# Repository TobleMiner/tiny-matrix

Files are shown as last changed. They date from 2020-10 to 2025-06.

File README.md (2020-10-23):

Tiny LED matrix
===============

This board is a tiny 8x8 monochrome LED matrix powered by a STM32F030. The board is
just 11x11mm in size and fully JLCPCB assembly ready. The board has been panelized
in a 2x3 grid to use the available space on JLC's PCBs more efficinetly.  
The device uses a novel, BGA style assembly procedure to achieve the smallest footprint
possible.

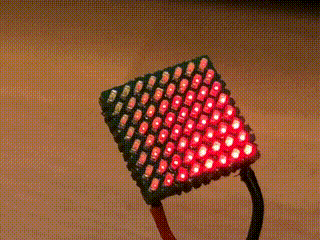
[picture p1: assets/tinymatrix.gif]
matrix animation showcase


# Ordering
When ordering through JLC there is a small tradeoff to be made. You can either order the
boards with 1mm thickness and will need to perform a small mechanical modification on
your TC2030 but get the smalles formfactor possible or order the boards in 1.6mm thickness
making your board stack thicker but sparing you from hacking up your TC2030.  
If you are not into placing components like A LOT I'd recommend using JLCs assembly service.

# Programming
The boards are fully functional while in the panel. I'd recommend leaving at least one
pair of boards inside the panel since the TC2030 cable can not be fixed to board easily
anymore once the board sandwich has been assembled.
Note that you might have to file down the allignment pins of the TC2030 if you want to
use it with assembled boards, since they are too long for the pogo pins to reach the pads
with a 1mm PCB.

# Assembly
While the matrix boards are fully functional while inside the frame they are intended to
be soldered back to back. To solder the boards together first remove them from the panel.
After that wet the backsides of the boards with a liberal amount of good quality flux.
Then drag a soldering iron wetted with lots of solder over the testpoints on the backside
of the board. This should create fairly uniform solder balls ontop of the pads. Once all
boards are preapred with solder balls apply more flux and stick one controller board and
one LED board together. Make sure they are alligned properly. Now you can reflow the two
boards together. You can do this either manually with hot air or in a reflow oven. Situate
the stacked boards LEDs down, since they are the most temperature sensitive parts. If you
have any level of familarity with soldering BGA components you will notice when reflow is
complete right away. Don't be afraid to heat the boards for a little longer, the STM32F030
seem to be able to take quite a lot of abuse.

# Firmware
The directory `firmware` contains a simple example displaying the pattern from the gif
above.

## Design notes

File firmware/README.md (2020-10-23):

Tinymatrix firmware
===================

A simple firmware example for the tinymatrix.

Requires arm-none-eabi toolchain.

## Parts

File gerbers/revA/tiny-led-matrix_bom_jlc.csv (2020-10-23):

Comment | Designator | Footprint | LCSC Part #
10uF | C1 | C_0402_1005Metric | C15525
100nF | C3,C2,C4 | C_0402_1005Metric | C1525
LED | D1,D2,D3,D4,D5,D6,D7,D8,D9,D10,D11,D12,D13,D14,D15,D16,D17,D18,D19,D20,D21,D22,D23,D24,D25,D26,D27,D28,D29,D30,D31,D32,D33,D34,D35,D36,D37,D38,D39,D40,D41,D42,D43,D44,D45,D46,D47,D48,D49,D50,D51,D52,D53,D54,D55,D56,D57,D58,D59,D60,D61,D62,D63,D64 | LED_0402_1005Metric | C165980
1kR | R1 | R_0402_1005Metric | C11702
1kR | RN1,RN2 | R_Array_Concave_4x0402 | C25726
STM32F030F4Px | U1 | TSSOP-20_4.4x6.5mm_P0.65mm | C89040

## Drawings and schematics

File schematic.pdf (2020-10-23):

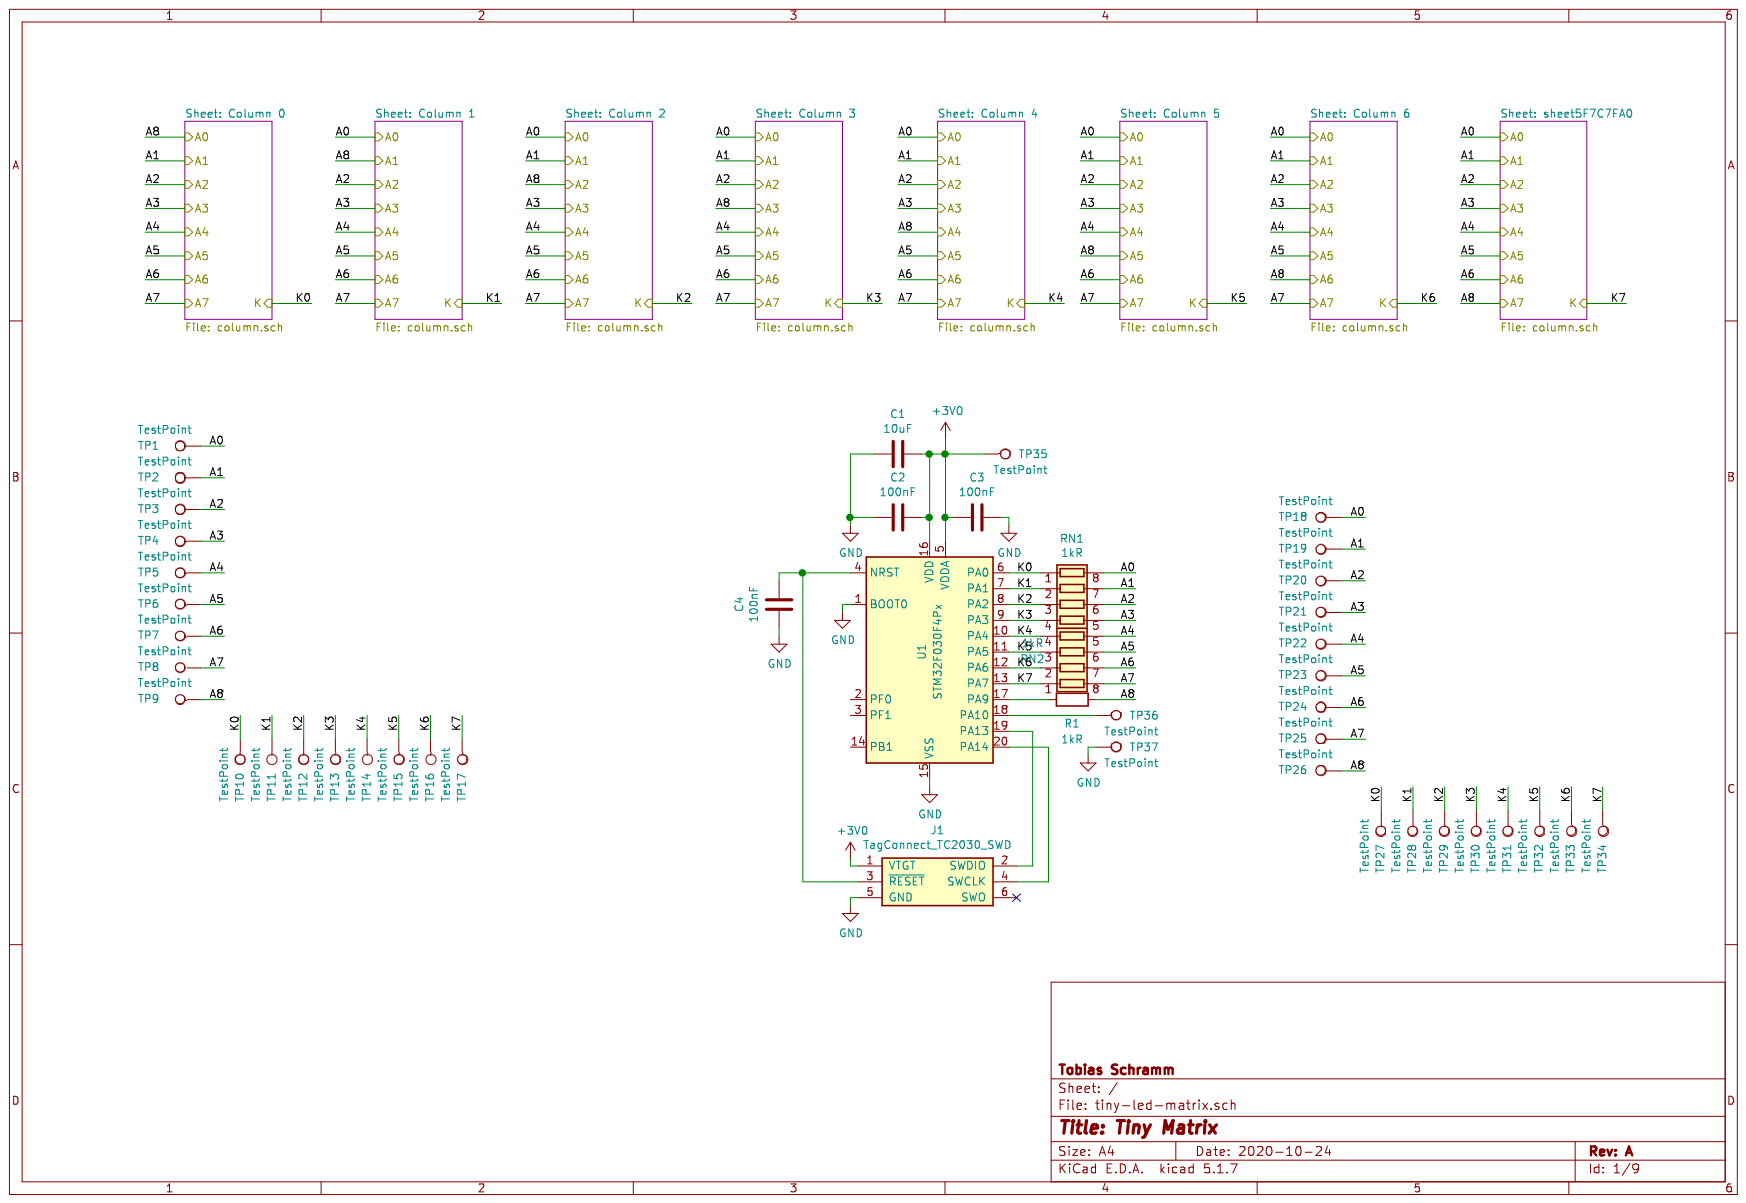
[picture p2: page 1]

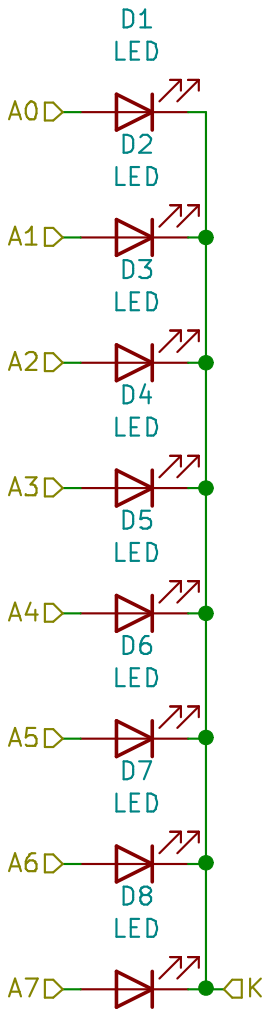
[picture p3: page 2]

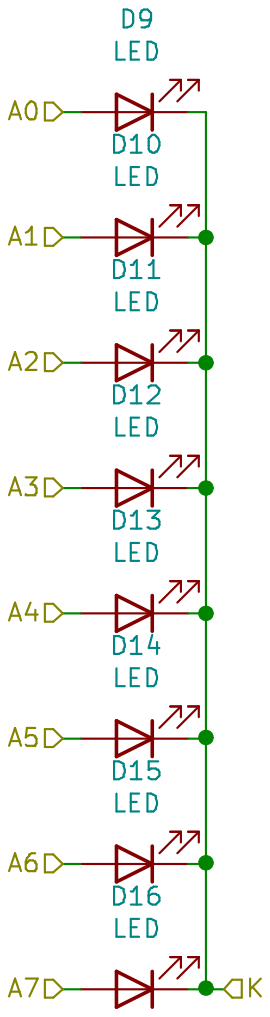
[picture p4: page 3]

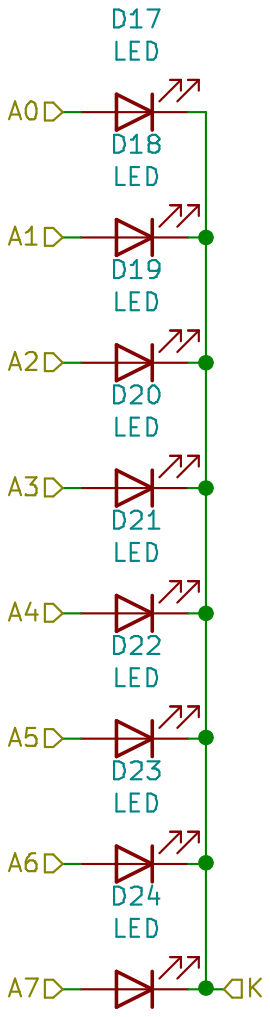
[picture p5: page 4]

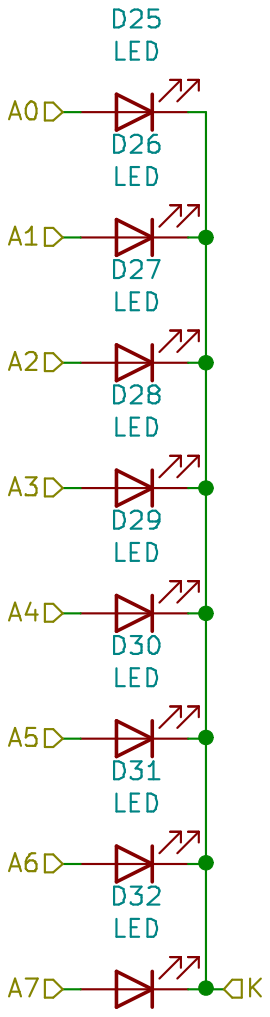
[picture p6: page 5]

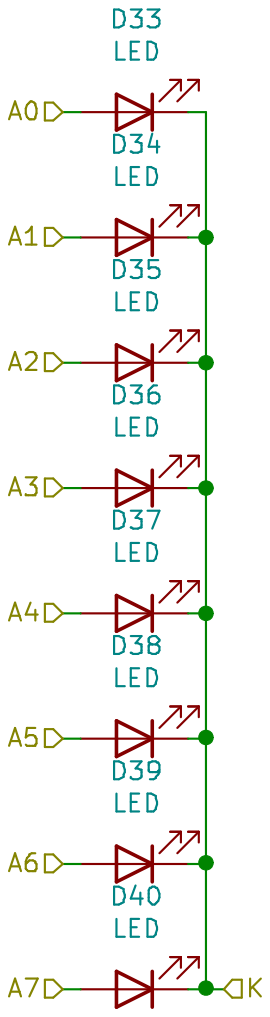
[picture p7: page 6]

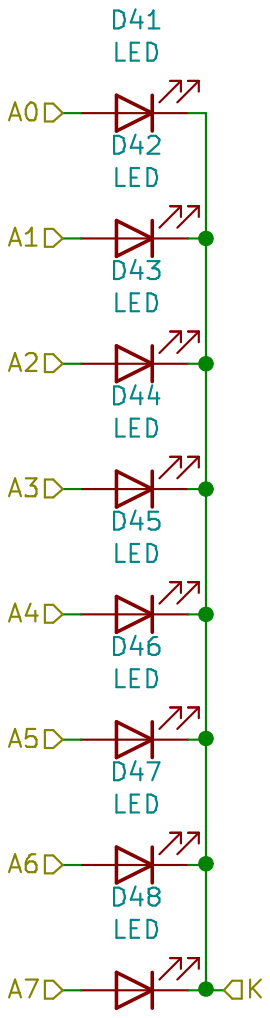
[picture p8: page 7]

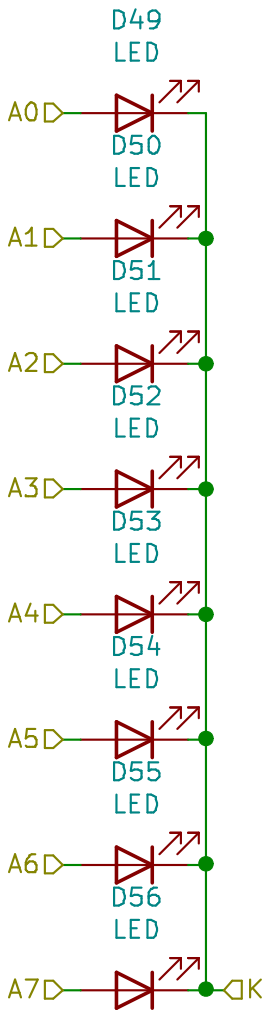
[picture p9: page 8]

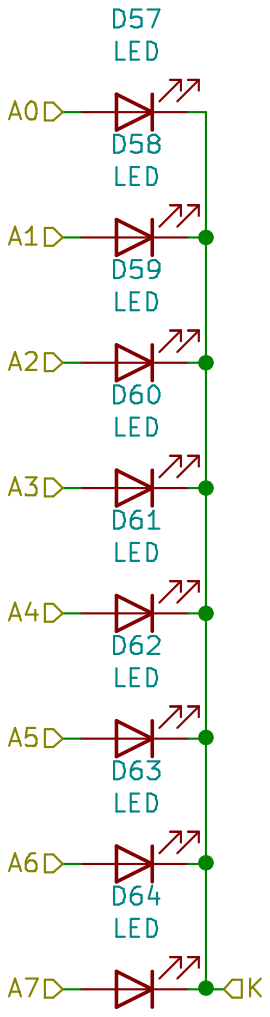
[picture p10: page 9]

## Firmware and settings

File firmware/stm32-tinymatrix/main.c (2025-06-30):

#include <stddef.h>
#include <stdbool.h>
#include <stdio.h>
#include <string.h>
#include <math.h>
#define M_PI 3.14159265358979323846264338328


#include <libopencm3/cm3/nvic.h>
#include <libopencm3/stm32/gpio.h>
#include <libopencm3/stm32/rcc.h>
#include <libopencm3/stm32/timer.h>

#include "game_of_life_vec32.h"
#include "rng.h"

#define ARRAY_SIZE(arr_) (sizeof((arr_)) / sizeof(*(arr_)))
#define ABS(x_) ((x_) > 0 ? (x_) : -(x_))

const uint8_t gamma8[] = {
    0,  0,  0,  0,  0,  0,  0,  0,  0,  0,  0,  0,  0,  0,  0,  0,
    0,  0,  0,  0,  0,  0,  0,  0,  0,  0,  0,  0,  1,  1,  1,  1,
    1,  1,  1,  1,  1,  1,  1,  1,  1,  2,  2,  2,  2,  2,  2,  2,
    2,  3,  3,  3,  3,  3,  3,  3,  4,  4,  4,  4,  4,  5,  5,  5,
    5,  6,  6,  6,  6,  7,  7,  7,  7,  8,  8,  8,  9,  9,  9, 10,
   10, 10, 11, 11, 11, 12, 12, 13, 13, 13, 14, 14, 15, 15, 16, 16,
   17, 17, 18, 18, 19, 19, 20, 20, 21, 21, 22, 22, 23, 24, 24, 25,
   25, 26, 27, 27, 28, 29, 29, 30, 31, 32, 32, 33, 34, 35, 35, 36,
   37, 38, 39, 39, 40, 41, 42, 43, 44, 45, 46, 47, 48, 49, 50, 50,
   51, 52, 54, 55, 56, 57, 58, 59, 60, 61, 62, 63, 64, 66, 67, 68,
   69, 70, 72, 73, 74, 75, 77, 78, 79, 81, 82, 83, 85, 86, 87, 89,
   90, 92, 93, 95, 96, 98, 99,101,102,104,105,107,109,110,112,114,
  115,117,119,120,122,124,126,127,129,131,133,135,137,138,140,142,
  144,146,148,150,152,154,156,158,160,162,164,167,169,171,173,175,
  177,180,182,184,186,189,191,193,196,198,200,203,205,208,210,213,
  215,218,220,223,225,228,231,233,236,239,241,244,247,249,252,255 };

static volatile uint8_t fb_g[8 * 8] = { 0 };

#define FIELD_COMPRESSION 1

/* Cycle through all LEDs, one at a time */
//#define LED_TEST
//#define SINE_FIELD
#define GAME_OF_LIFE

#define IRQ_DRIVEN_DISPLAY

#ifdef GAME_OF_LIFE
static game_of_life_vec32_t game_of_life;
static uint8_t population_history_idx = 0;
static uint16_t population_history[32] = { 0 };
static uint16_t population_history_downsampler = 0;
static uint16_t population_randomization_cnt = 0;
#endif

#ifdef SINE_FIELD
#define FIELD_SIZE 16
uint8_t sine_field_g[FIELD_SIZE * FIELD_SIZE];
#endif

volatile bool display_done = false;

static void clock_init(void) {
	//rcc_clock_setup_in_hsi_out_48mhz();
/*
	rcc_set_hpre(RCC_CFGR_HPRE_DIV2);
	rcc_apb1_frequency /= 2;
	rcc_ahb_frequency /= 2;
*/
	rcc_periph_clock_enable(RCC_GPIOA);
	rcc_periph_clock_enable(RCC_GPIOB);
	rcc_periph_clock_enable(RCC_TIM1);
	nvic_enable_irq(NVIC_TIM1_BRK_UP_TRG_COM_IRQ);
	timer_enable_irq(TIM1, TIM_DIER_UIE);
	timer_direction_down(TIM1);
	timer_set_prescaler(TIM1, rcc_apb1_frequency / 1000000UL);
	TIM1_CNT = 8;
	timer_enable_counter(TIM1);
}

#define TIM14 TIM14_BASE

static void place_acorn(unsigned int x, unsigned int y) {
	game_of_life_vec32_set_cell(&game_of_life, x + 1, y + 0, true);
	game_of_life_vec32_set_cell(&game_of_life, x + 3, y + 1, true);
	game_of_life_vec32_set_cell(&game_of_life, x + 0, y + 2, true);
	game_of_life_vec32_set_cell(&game_of_life, x + 1, y + 2, true);
	game_of_life_vec32_set_cell(&game_of_life, x + 4, y + 2, true);
	game_of_life_vec32_set_cell(&game_of_life, x + 5, y + 2, true);
	game_of_life_vec32_set_cell(&game_of_life, x + 6, y + 2, true);
}

int main(void) {
	int off_x = 0, off_y = 0, cycles = 0;
	int led_count = 0;

	clock_init();
	rng_init(0x42);

#ifdef GAME_OF_LIFE
	game_of_life_vec32_init(&game_of_life);
	place_acorn(29, 31);
#endif

#ifdef SINE_FIELD
	/* Generate sine field */
	for (int y = 0; y < FIELD_SIZE; y++) {
		for (int x = 0; x < FIELD_SIZE; x++) {
			float sinx = sinf(x * M_PI * FIELD_COMPRESSION / (FIELD_SIZE - 1));
			float siny = sinf(y * M_PI * FIELD_COMPRESSION / (FIELD_SIZE - 1));
			float prod = sinx * siny;

			sine_field_g[y * FIELD_SIZE + x] = gamma8[(uint8_t)roundf(fabs(prod * 255))];
		}
	}
#endif

	unsigned int num_sim_steps = 0;
	unsigned int game_row = 0;
	while(1) {
		uint8_t x, y, bit;

#ifdef LED_TEST
		if (display_done) {
			fb_g[led_count] = 0;
			led_count++;
			led_count %= 64;
			fb_g[led_count] = 255;
			display_done = false;
		}
#endif
		if (!cycles) {
#ifdef SINE_FIELD
			for (y = 0; y < 8; y++) {
				for (x = 0; x < 8; x++) {
					int x_wrapped = (off_x + x) % FIELD_SIZE;
					int y_wrapped = (off_y + y) % FIELD_SIZE;
					fb_g[y * 8 + x] = sine_field_g[y_wrapped * FIELD_SIZE + x_wrapped];
				}
			}
			off_x++;
			off_y++;
			off_x %= FIELD_SIZE;
			off_y %= FIELD_SIZE;
#endif
			cycles++;
		}

#ifdef GAME_OF_LIFE
		game_of_life_vec32_step(&game_of_life);
		unsigned int total_alive_cells = 0;
		for (y = 0; y < 8; y++) {
			for (x = 0; x < 8; x++) {
				uint8_t num_alive_cells = game_of_life_vec32_count_alive_cells_in_8x8_aligned_area(&game_of_life, x * 8, y * 8);
				total_alive_cells += num_alive_cells;
				if (num_alive_cells) {
					fb_g[y * 8 + x] = num_alive_cells - 1;
				} else {
					fb_g[y * 8 + x] = 0;
				}
			}
		}

		population_history_downsampler++;
		if (population_history_downsampler >= 4) {
			population_history_downsampler = 0;
			population_history[population_history_idx++] = total_alive_cells;

			if (population_history_idx == ARRAY_SIZE(population_history)) {
				population_history_idx = 0;

				unsigned int population_delta = 0;
				for (unsigned int i = 0; i < ARRAY_SIZE(population_history) - 1; i++) {
					population_delta += ABS((int)population_history[i] - (int)population_history[i + 1]);
				}

				if (population_delta < GAME_OF_LIFE_VEC32_WIDTH * GAME_OF_LIFE_VEC32_HEIGHT / 10) {
					uint32_t pos_x = rng_u32() % (GAME_OF_LIFE_VEC32_WIDTH - 10);
					uint32_t pos_y = rng_u32() % (GAME_OF_LIFE_VEC32_HEIGHT - 5);
					place_acorn(pos_x, pos_y);
				}
			}
		}

		population_randomization_cnt++;
		if (population_randomization_cnt >= 60UL * 300) {
			population_randomization_cnt = 0;
			uint32_t pos_x = rng_u32() % (GAME_OF_LIFE_VEC32_WIDTH - 10);
			uint32_t pos_y = rng_u32() % (GAME_OF_LIFE_VEC32_HEIGHT - 5);
			place_acorn(pos_x, pos_y);
		}
#endif

#ifndef IRQ_DRIVEN_DISPLAY
		/* 8 loop cycles for 8 bits, exponentially increasing duration */
		for (bit = 0; bit < 8; bit++) {
			/* display is multiplexed over rows */
			for (y = 0; y < 8; y++) {
				unsigned int i;
				uint16_t row = 0;

				for (x = 0; x < 8; x++) {
					/* Set output bit if current brightness bit is set, too */
					if (fb_g[y * 8 + x] & (1 << bit)) {
						row |= (1 << x);
					}
				}
				/* Anode pin mapped to cathode of this row is on PA9 */
				if (row & (1 << y)) {
					row |= 1 << 9;
				}
				row &= ~(1 << y);
				/* Set all outputs to zero to prevent ghosting */
				gpio_port_write(GPIOA, 0);
				/* Setup hi-z pins first */
				gpio_mode_setup(GPIOA, GPIO_MODE_INPUT, GPIO_PUPD_NONE, ~(row | (1 << y)) & 0x02ff);
				/* Setup outputs */
				gpio_mode_setup(GPIOA, GPIO_MODE_OUTPUT, GPIO_PUPD_NONE, row | (1 << y));
				/* Set output values */
				gpio_port_write(GPIOA, row);

				for (i = 0; i < (16U << bit); i++) __asm("nop;");
			}
		}
#endif
/*
		if (display_done) {
			display_done = false;
			cycles++;
		}
*/
#ifdef LED_TEST
		cycles %= 30;
#else
		cycles %= 11;
#endif
	}

	return 0;
}

#ifdef IRQ_DRIVEN_DISPLAY
static volatile uint8_t display_bit = 0;
uint8_t volatile display_y = 0;

void tim1_brk_up_trg_com_isr() {
	timer_disable_counter(TIM1);

	uint16_t row = 0;
	for (uint8_t x = 0; x < 8; x++) {
		/* Set output bit if current brightness bit is set, too */
		if (fb_g[display_y * 8 + x] & (1 << display_bit)) {
			row |= (1 << x);
		}
	}
	/* Anode pin mapped to cathode of this row is on PA9 */
	if (row & (1 << display_y)) {
		row |= 1 << 9;
	}
	row &= ~(1 << display_y);
	/* Set all outputs to zero to prevent ghosting */
	gpio_port_write(GPIOA, 0);
	/* Setup hi-z pins first */
	gpio_mode_setup(GPIOA, GPIO_MODE_INPUT, GPIO_PUPD_NONE, ~(row | (1 << display_y)) & 0x02ff);
	/* Setup outputs */
	gpio_mode_setup(GPIOA, GPIO_MODE_OUTPUT, GPIO_PUPD_NONE, row | (1 << display_y));
	/* Set output values */
	gpio_port_write(GPIOA, row);

	TIM1_CNT = 16U << display_bit;
	timer_clear_flag(TIM1, TIM_SR_UIF);
	timer_enable_counter(TIM1);

	display_y++;
	if (display_y >= 8) {
		display_y = 0;
		display_bit++;
		if (display_bit >= 6) {
			display_bit = 0;
			display_done = true;
		}
	}
}
#endif

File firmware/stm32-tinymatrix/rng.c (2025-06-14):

#include "rng.h"

#include <libopencm3/stm32/rcc.h>
#include <libopencm3/stm32/adc.h>

#define RNG_LFSR_TAPS 0x04C11DB7

static uint32_t rng_state = 0;

static void rng_update(const void *data, unsigned int len) {
	const uint8_t *data8 = data;
	while (len--) {
		uint8_t byt = *data8++;
		for (uint8_t bitpos = 0; bitpos < 8; bitpos++) {
			if (((rng_state >> 31) & 1) == ((byt >> bitpos) & 1)) {
				rng_state = (rng_state << 1);
			} else {
				rng_state = (rng_state << 1) ^ RNG_LFSR_TAPS;
			}
		}
	}
}

void rng_init(uint32_t seed) {
	rcc_periph_clock_enable(RCC_ADC);
	adc_calibrate(ADC);
	adc_set_sample_time_on_all_channels(ADC, ADC_SMPTIME_239DOT5);
	uint8_t conversion_channels[] = { 9 };
	adc_set_regular_sequence(ADC, sizeof(conversion_channels), conversion_channels);
	ADC1_CFGR2 |= ADC_CLKSOURCE_PCLK_DIV4;
	adc_power_on(ADC);
	adc_start_conversion_regular(ADC);
	rng_update(&seed, 4);
}

uint32_t rng_u32(void) {
	uint32_t res = rng_state;
	uint16_t adc_data = adc_read_regular(ADC);
	rng_update(&adc_data, sizeof(adc_data));
	return res;
}

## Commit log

2020-10-06 Panelize single unit
    [tiny-led-matrix.kicad_pcb]
2020-10-06 Full panel
    [tiny-led-matrix.kicad_pcb]
2020-10-23 Update board fab settings
    [tiny-led-matrix.kicad_pcb]
2020-10-23 Add fabrication files
    [tiny-led-matrix_bom_jlc.csv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]
2020-10-23 Add schematic pdf export
    [column.sch, tiny-led-matrix.sch]
2025-06-14 Spawn random acorns to prevent persistence of visually boring patterns
    [main.c]
2025-06-30 Switch to vec32 game of life implementation
2025-06-30 Switch to 6 bit grayscale and downclock MCU to 8MHz
